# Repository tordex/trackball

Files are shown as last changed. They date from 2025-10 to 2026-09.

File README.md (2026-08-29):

# Tordex Trackball Firmware

Firmware for a custom ESP32-S3 wireless trackball using a PAW3395 optical sensor and BLE HID.

## Highlights

- BLE HID mouse
- PAW3395 motion sensor (SPI)
- SSD1306 OLED status/config UI (I2C)
- Battery monitoring and BLE battery level reporting
- Vertical and horizontal scrolling
- High-resolution scrolling mode
- DPI presets switchable from hardware button
- Deep sleep on inactivity with GPIO wakeup

## Hardware

- MCU: ESP32-S3
- Sensor: PAW3395
- Display: SSD1306 OLED (I2C address `0x3C`)
- Buttons: 6 total
	- `BTN1`, `BTN2`, `BTN3` (main mouse buttons)
	- `MODE` (scroll mode toggle)
	- `SCROLL` (hold/lock scroll and button lock behavior)
	- `CFG` (DPI preset switch)

Pin mapping is defined in `main/pins.h`.

## Software Requirements

- ESP-IDF `v5.5.x`
- CMake `>= 3.16`

## Build and Flash

1. Open an ESP-IDF environment shell.
2. Set target (first time only):

```bash
idf.py set-target esp32s3
```

3. Build:

```bash
idf.py build
```

4. Flash:

```bash
idf.py -p <PORT> flash
```

5. Optional monitor:

```bash
idf.py -p <PORT> monitor
```

## Runtime Controls

### Pointer

- Roll the trackball to move the pointer.

### Scrolling

- Hold `SCROLL` and roll the ball: temporary scroll mode.
- Click `SCROLL`: toggle locked scroll mode on/off.

### Button Lock (drag lock)

- Press and hold a mouse button.
- Click `SCROLL` to lock that button state.
- Click `SCROLL` again to release all locked buttons.

### DPI Preset

- Click `CFG` to cycle DPI presets.
- Hold `CFG` for one second to forget all saved Bluetooth pairings.

### Scroll Mode and Hi-Res

- Click `MODE` to cycle scroll axis modes:
	- vertical + horizontal
	- vertical only
	- horizontal only
- Hold `MODE` to toggle high-resolution scrolling.

## Project Structure

- `main/app.cpp`: app state machine, input handling, power management
- `main/paw3395/`: PAW3395 sensor driver
- `main/nimble/`: BLE HID implementation
- `main/oled/`: SSD1306 driver and UI rendering
- `main/battery/`: battery measurement and level updates
- `main/button/`: button handling (click/hold/state)

## Configuration Notes

- Build-time settings are in `sdkconfig` and `sdkconfig.defaults`.
- Project-specific Kconfig entries are in `main/Kconfig.projbuild`.
- The default deep sleep timeout is 3 minutes (`180000 ms`) in app config.

## Troubleshooting

- Build fails with missing IDF tools:
	- verify ESP-IDF is exported correctly in your shell
- No serial port found:
	- check cable/data support and device permissions
- Device not discoverable over BLE:
	- erase/reflash and reset the board
	- confirm power and battery voltage are stable

## License

This project is licensed under the MIT License. See [LICENSE](LICENSE) for details.

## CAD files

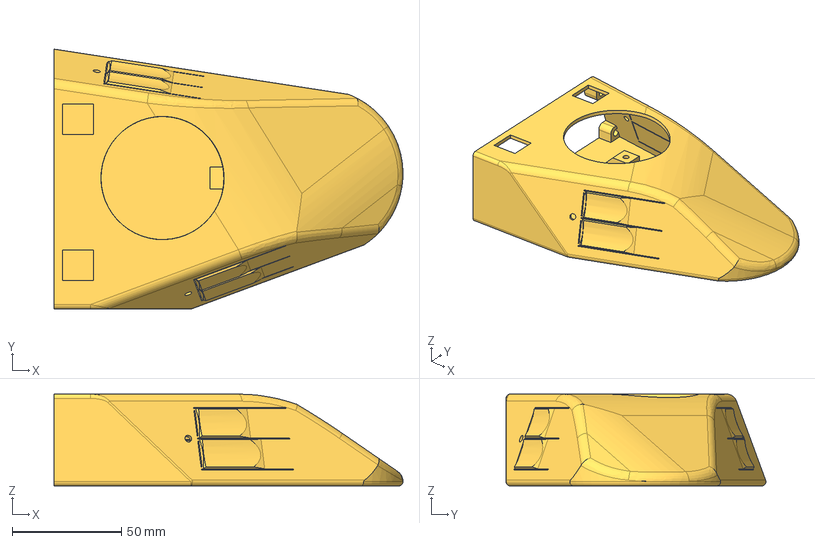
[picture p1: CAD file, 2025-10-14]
hardware/3d/horizontal/Trackball Base - Case v5.step
160.0 x 119.1 x 42.1 mm

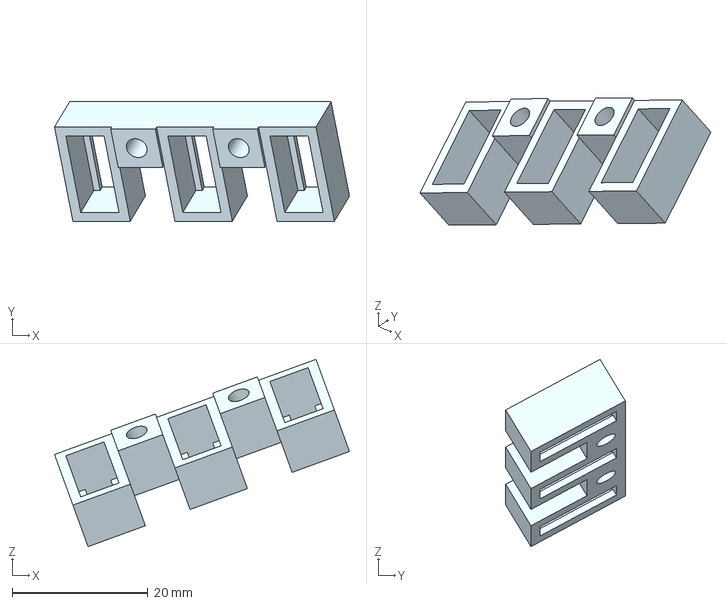
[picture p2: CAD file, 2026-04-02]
hardware/3d/vertical/Vertical - Clickers Holder.step
43.5 x 17.6 x 27.6 mm

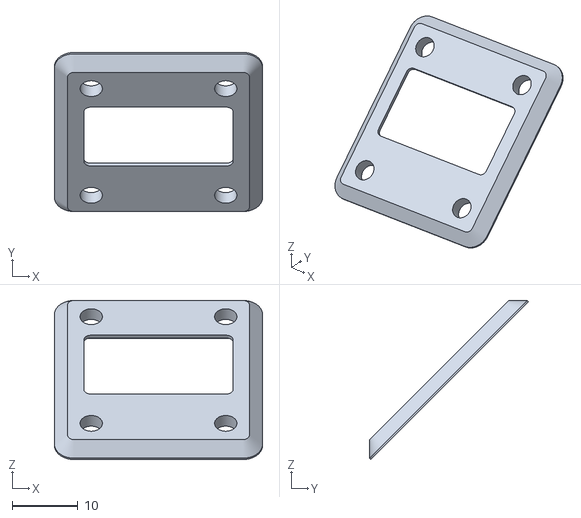
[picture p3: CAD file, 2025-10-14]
hardware/3d/horizontal/OLED Cover.stl
31.7 x 24.3 x 24.3

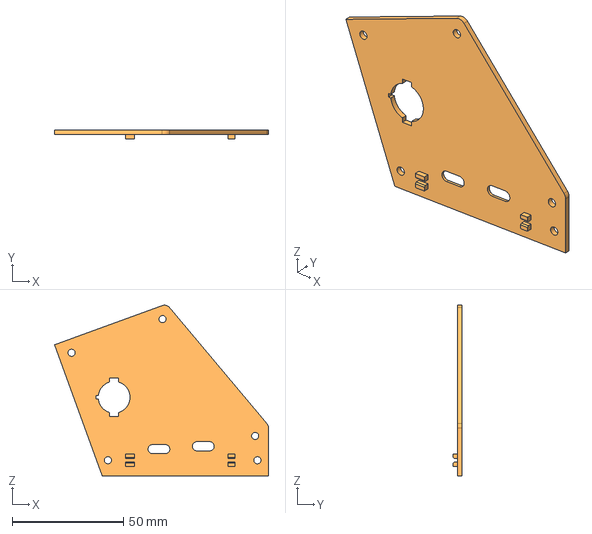
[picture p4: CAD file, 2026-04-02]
hardware/3d/vertical/Vertical - Wall cover.step
96.4 x 4.00 x 76.8 mm

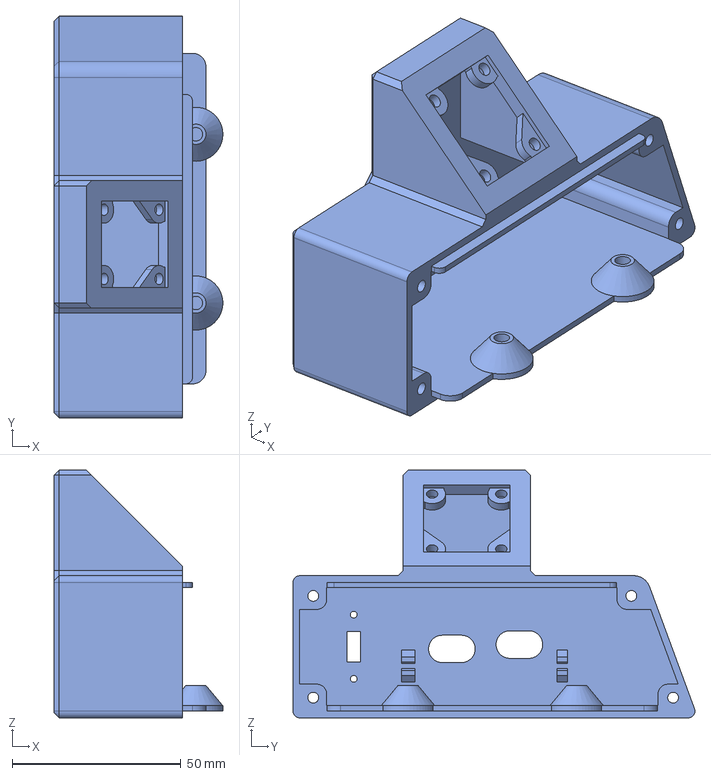
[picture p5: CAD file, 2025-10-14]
hardware/3d/horizontal/Trackball Base - PCB Case.step
50.0 x 119.1 x 73.4 mm

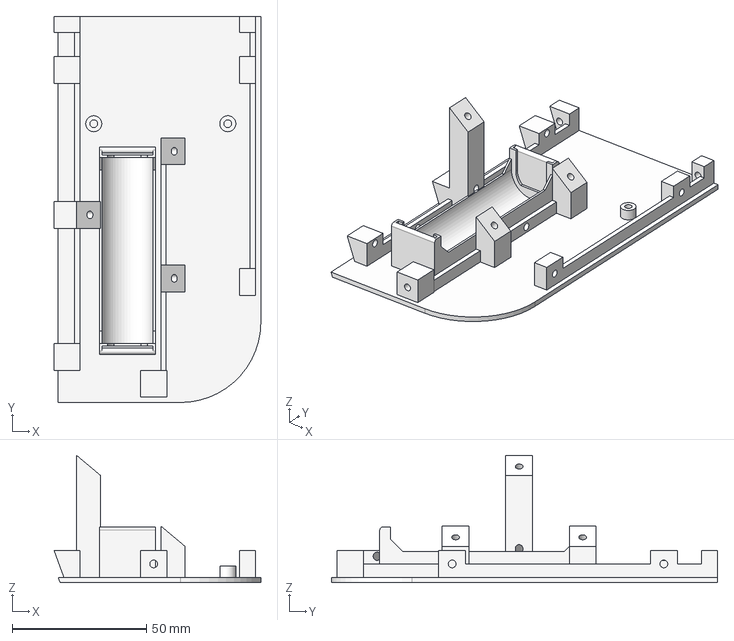
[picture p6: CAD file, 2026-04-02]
hardware/3d/vertical/Vertical - Bottom.step
77.1 x 144.0 x 47.5 mm

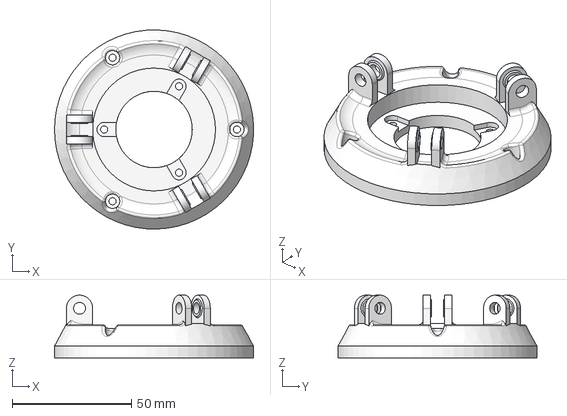
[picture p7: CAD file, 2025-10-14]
hardware/3d/horizontal/Trackball Base - Ball Mount.step
83.4 x 83.5 x 26.3 mm

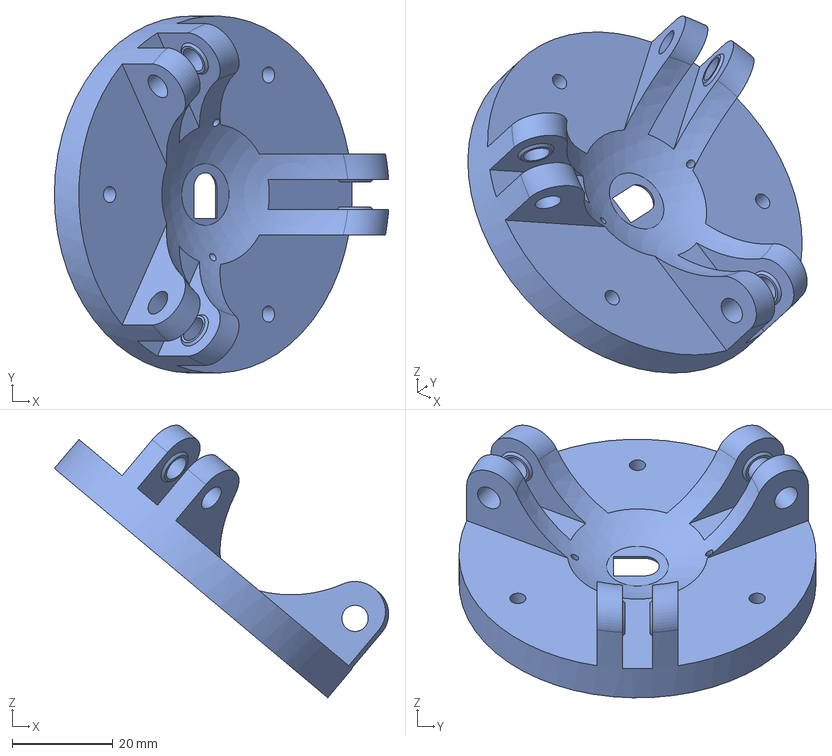
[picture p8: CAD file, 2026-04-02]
hardware/3d/vertical/Vertical - Ball Holder.step
66.2 x 70.7 x 54.0 mm

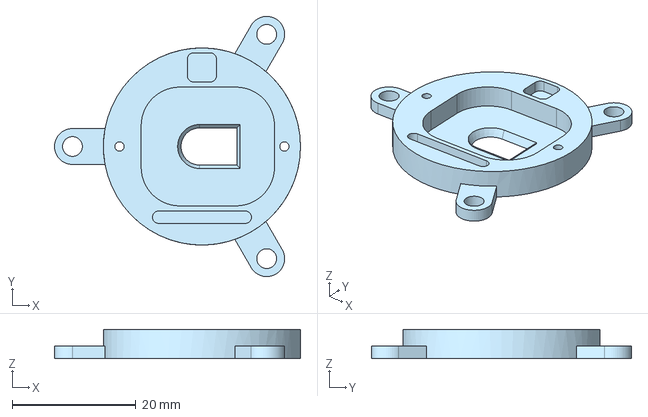
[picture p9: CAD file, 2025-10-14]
hardware/3d/horizontal/Module - Module Mount.step
39.8 x 42.0 x 4.70 mm

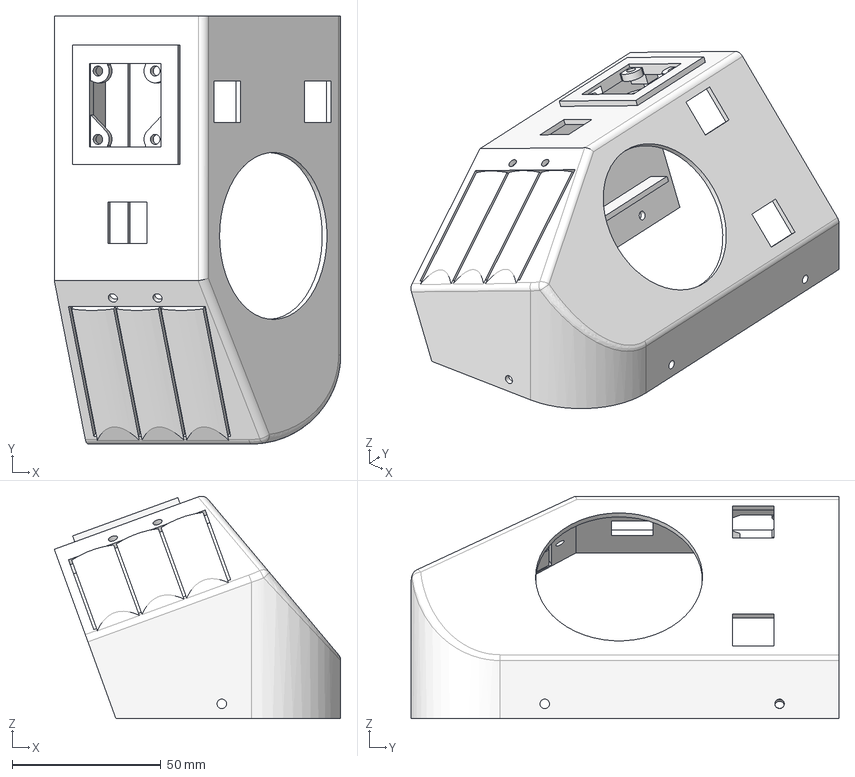
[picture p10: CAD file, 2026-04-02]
hardware/3d/vertical/Vertical - Cover.step
96.4 x 144.0 x 74.8 mm

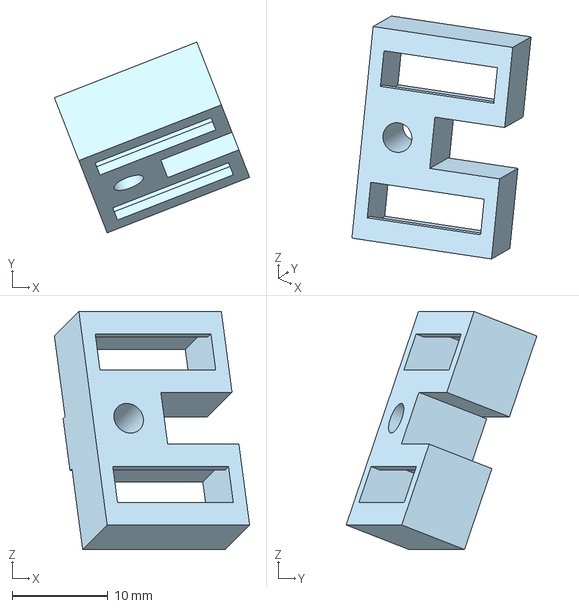
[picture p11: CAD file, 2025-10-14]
hardware/3d/horizontal/Trackball Base - Buttons Mount v4.step
20.4 x 20.0 x 24.9 mm

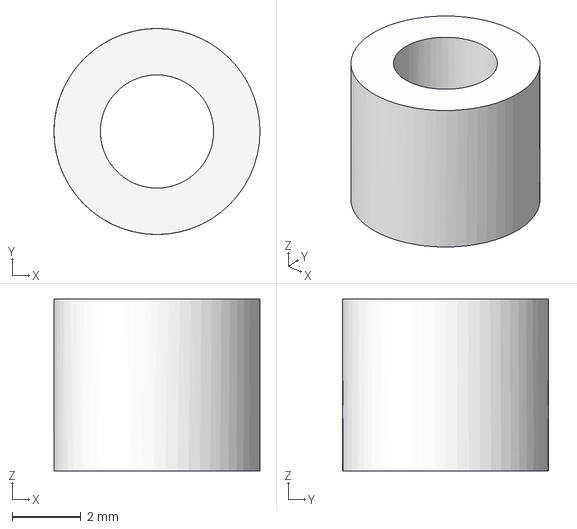
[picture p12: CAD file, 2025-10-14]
hardware/3d/horizontal/Trackball Base - PCB spacer.step
6.00 x 6.00 x 5.00 mm

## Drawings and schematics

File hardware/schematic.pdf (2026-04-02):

# IO7 10 IO8 11 IO9 12 IO10 13 IO11 14 IO12 15 IO13 16 RX 17 TX 18

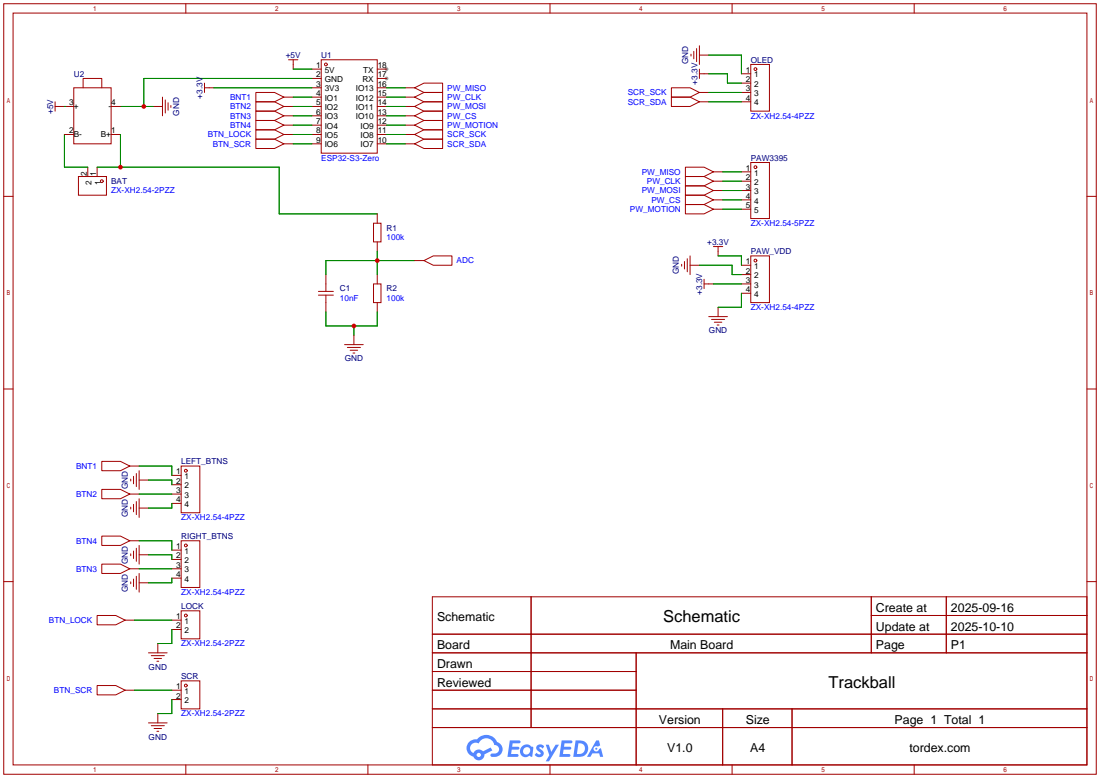
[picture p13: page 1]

Schematic | Schematic | Create at | 2025-09-16

Update at | 2025-10-10

Board | Main Board | Page | P1
Drawn | | Trackball
Reviewed

Version | Size | Page 1 Total 1
V1.0 | A4 | tordex.com

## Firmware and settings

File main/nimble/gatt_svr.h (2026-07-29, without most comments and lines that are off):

#define H_BLEPRPH_
#include <stdbool.h>
#include "nimble/ble.h"
#include "host/ble_hs.h"
#include "host/ble_uuid.h"
#include "services/gatt/ble_svc_gatt.h"
#include "services/gap/ble_svc_gap.h"
#include "services/bas/ble_svc_bas.h"
#include "svc_dis.h"
#include "esp_nimble_hci.h"
#include "nimble/nimble_port.h"
#include "nimble/nimble_port_freertos.h"
#include "host/util/util.h"
#include "modlog/modlog.h"
#ifdef __cplusplus
extern "C"
{
#endif
#define GATT_SVR_SVC_ALERT_UUID               0x1811
#define GATT_SVR_CHR_SUP_NEW_ALERT_CAT_UUID   0x2A47
#define GATT_SVR_CHR_NEW_ALERT                0x2A46
#define GATT_SVR_CHR_SUP_UNR_ALERT_CAT_UUID   0x2A48
#define GATT_SVR_CHR_UNR_ALERT_STAT_UUID      0x2A45
#define GATT_SVR_CHR_ALERT_NOT_CTRL_PT        0x2A44
#define GATT_UUID_HID_SERVICE                 0x1812
#define GATT_UUID_HID_INFORMATION             0x2A4A
#define GATT_UUID_HID_REPORT_MAP              0x2A4B
#define GATT_UUID_HID_CONTROL_POINT           0x2A4C
#define GATT_UUID_HID_REPORT                  0x2A4D
#define GATT_UUID_HID_PROTO_MODE              0x2A4E
#define GATT_UUID_HID_BT_MOUSE_INPUT          0x2A33
#define GATT_UUID_BAT_PRESENT_DESCR           0x2904
#define GATT_UUID_EXT_RPT_REF_DESCR           0x2907
#define GATT_UUID_RPT_REF_DESCR               0x2908
#define BLE_SVC_DIS_MODEL_NUMBER_DEFAULT      "0x0102"
#define BLE_SVC_DIS_SERIAL_NUMBER_DEFAULT     "0x0001"
#define BLE_SVC_DIS_FIRMWARE_REVISION_DEFAULT "0x1409"
#define BLE_SVC_DIS_HARDWARE_REVISION_DEFAULT "0x0001"
#define BLE_SVC_DIS_SOFTWARE_REVISION_DEFAULT "0x1409"
#define BLE_SVC_DIS_MANUFACTURER_NAME_DEFAULT "tordex"
#define BLE_SVC_DIS_SYSTEM_ID_DEFAULT         "esp32"
#define BLE_SVC_DIS_PNP_INFO_DEFAULT                                                                                   \
    {0x04, 0x24, 0x56, 0x00, 0x01, 0x00, 0x01}
#define BLE_SVC_DIS_MODEL_NUMBER_READ_PERM      0
#define BLE_SVC_DIS_SERIAL_NUMBER_READ_PERM     0
#define BLE_SVC_DIS_HARDWARE_REVISION_READ_PERM 0
#define BLE_SVC_DIS_FIRMWARE_REVISION_READ_PERM 0
#define BLE_SVC_DIS_SOFTWARE_REVISION_READ_PERM 0
#define BLE_SVC_DIS_MANUFACTURER_NAME_READ_PERM 0
#define BLE_SVC_DIS_SYSTEM_ID_READ_PERM         0
#define HID_PROTOCOL_MODE_LEN                   1 // HID Protocol Mode
#define HID_INFORMATION_LEN                     4 // HID Information
#define HID_REPORT_REF_LEN                      2 // HID Report Reference Descriptor
#define HID_EXT_REPORT_REF_LEN                  2 // External Report Reference Descriptor
#define HID_RPT_ID_MOUSE_IN                     1 // Mouse input report ID from report map
#define HID_RPT_ID_FEATURE                      1 // Feature report ID from report map
#define HID_BOOT_MOUSE_IN                       8 // Mouse input report ID
#define HID_REPORT_TYPE_INPUT                   1
#define HID_REPORT_TYPE_OUTPUT                  2
#define HID_REPORT_TYPE_FEATURE                 3
#define HID_CC_RPT_SET_NUMERIC(s, x)                                                                                   \
    (s)[0] &= HID_CC_RPT_NUMERIC_BITS;                                                                                 \
    (s)[0] |= (x)
#define HID_CC_RPT_SET_CHANNEL(s, x)                                                                                   \
    (s)[0] &= HID_CC_RPT_CHANNEL_BITS;                                                                                 \
    (s)[0] |= ((x) & 0x03) << 4
#define HID_CC_RPT_SET_VOLUME(s, x)                                                                                    \
    (s)[0] &= HID_CC_RPT_VOLUME_BITS;                                                                                  \
    (s)[0] |= (x)
#define HID_CC_RPT_SET_BUTTON(s, x)                                                                                    \
    (s)[1] &= HID_CC_RPT_BUTTON_BITS;                                                                                  \
    (s)[1] |= (x)
#define HID_CC_RPT_SET_SELECTION(s, x)                                                                                 \
    (s)[1] &= HID_CC_RPT_SELECTION_BITS;                                                                               \
    (s)[1] |= ((x) & 0x03) << 4
#define HIDD_LE_REPORT_MOUSE_SIZE      (9)
#define HIDD_LE_BATTERY_LEVEL_SIZE     (1)
#define HIDD_LE_REPORT_FEATURE         (1)
#define HID_FLAGS_REMOTE_WAKE          0x01 // RemoteWake
#define HID_FLAGS_NORMALLY_CONNECTABLE 0x02 // NormallyConnectable
#define HID_CMD_SUSPEND                0x00 // Suspend
#define HID_CMD_EXIT_SUSPEND           0x01 // Exit Suspend
#define HID_PROTOCOL_MODE_BOOT         0x00 // Boot Protocol Mode
#define HID_PROTOCOL_MODE_REPORT       0x01 // Report Protocol Mode
#define HID_KBD_FLAGS                  HID_FLAGS_REMOTE_WAKE
#define HI_UINT16(a)                   (((a) >> 8) & 0xFF)
#define LO_UINT16(a)                   ((a) & 0xFF)
#define DEFAULT_MIN_KEY_SIZE           0
#define NVS_IO_CAP_NUM                 "io_cap_number"
#define DEFAULT_IO_CAP                 BLE_HS_IO_NO_INPUT_OUTPUT
#define HID_MOUSE_APPEARENCE           0x03c2 // appearance field in advertising packet
    struct ble_hs_cfg;
    struct ble_gatt_register_ctxt;
    struct prf_char_pres_fmt
    {
        uint8_t format;
        uint8_t exponent;
        uint16_t unit;
        uint8_t name_space;
        uint16_t description;
    } __attribute__((packed));
    enum attr_handles
    {
        HANDLE_BATTERY_LEVEL,         //  0
        HANDLE_DIS_MODEL_NUMBER,      //  1
        HANDLE_DIS_SERIAL_NUMBER,     //  2
        HANDLE_DIS_HARDWARE_REVISION, //  3
        HANDLE_DIS_FIRMWARE_REVISION, //  4
        HANDLE_DIS_SOFWARE_REVISION,  //  5
        HANDLE_DIS_MANUFACTURER_NAME, //  6
        HANDLE_DIS_SYSTEM_ID,         //  7
        HANDLE_DIS_PNP_INFO,          //  8
        HANDLE_HID_INFORMATION,       //  9
        HANDLE_HID_CONTROL_POINT,     // 10
        HANDLE_HID_REPORT_MAP,        // 11
        HANDLE_HID_PROTO_MODE,        // 12
        HANDLE_HID_MOUSE_REPORT,      // 13
        HANDLE_HID_BOOT_MOUSE_REPORT, // 19
        HANDLE_HID_FEATURE_REPORT,    // 20
        HANDLE_HID_COUNT              // 21
    };
    struct report_reference_table
    {
        int     id;
        uint8_t hidReportRef[HID_REPORT_REF_LEN];
    } __attribute__((packed));
    void gatt_svr_register_cb(struct ble_gatt_register_ctxt* ctxt, void* arg);
    int  gatt_svr_init(void);
    void gatt_svr_deinit(void);
    int hid_svr_chr_access(uint16_t conn_handle, uint16_t attr_handle, struct ble_gatt_access_ctxt* ctxt, void* arg);
    int ble_svc_report_access(uint16_t conn_handle, uint16_t attr_handle, struct ble_gatt_access_ctxt* ctxt, void* arg);
    int ble_svc_battery_access(uint16_t conn_handle, uint16_t attr_handle, struct ble_gatt_access_ctxt* ctxt,
                               void* arg);
    int ble_svc_dis_access(uint16_t conn_handle, uint16_t attr_handle, struct ble_gatt_access_ctxt* ctxt, void* arg);
    extern const uint8_t Hid_report_map[];
    extern size_t Hid_report_map_size;
    extern uint16_t Svc_char_handles[];
    extern const struct ble_gatt_svc_def Gatt_svr_included_services[];
    extern const struct ble_gatt_svc_def Gatt_svr_svcs[];
    extern const uint8_t HidInfo[];
    extern uint16_t HidExtReportRefDesc;
    extern uint8_t  HidProtocolMode;
    extern struct report_reference_table Hid_report_ref_data[];
    extern size_t                        Hid_report_ref_data_count;
    extern struct prf_char_pres_fmt Battery_level_units;
    extern struct ble_svc_dis_data Hid_dis_data;
#ifdef __cplusplus
}
#endif

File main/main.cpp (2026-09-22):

#include <stdio.h>
#include <stdlib.h>
#include <string.h>
#include "freertos/FreeRTOS.h"
#include "freertos/task.h"
#include "freertos/event_groups.h"
#include "esp_system.h"
#include "esp_wifi.h"
#include "esp_event.h"
#include "esp_log.h"
#include "paw3395.h"
#include "pins.h"
#include <freertos/queue.h>
#include "button.h"
#include "hid_func.h"
#include "app.h"

app* g_app = nullptr;

void hid_on_connection_changed()
{
    g_app->send_event(app_event_update_connection_state);
}

extern "C" void app_main(void)
{
    esp_log_level_set("NimBLE", ESP_LOG_WARN);
    // esp_log_level_set(HID_DEMO_TAG, ESP_LOG_MAX);
    // esp_log_level_set("BLE_HID_MOUSE", ESP_LOG_MAX);

    gpio_install_isr_service(0);

    g_app = new app();
    g_app->init();
    g_app->loop();
}

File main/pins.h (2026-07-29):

#ifndef __PINS__H__
#define __PINS__H__

#define PIN_NUM_MISO    GPIO_NUM_13
#define PIN_NUM_MOSI    GPIO_NUM_11
#define PIN_NUM_CLK     GPIO_NUM_12
#define PIN_NUM_CS      GPIO_NUM_10
#define PIN_NUM_MOTION  GPIO_NUM_9

#define PIN_NUM_I2C_SDA GPIO_NUM_7
#define PIN_NUM_I2C_SCL GPIO_NUM_8

#define PIN_BTN1        GPIO_NUM_1
#define PIN_BTN2        GPIO_NUM_2
#define PIN_BTN3        GPIO_NUM_3
#define PIN_BTN_MODE    GPIO_NUM_6
#define PIN_BTN_SCROLL  GPIO_NUM_5
#define PIN_BTN_CFG     GPIO_NUM_4

#endif // __PINS__H__

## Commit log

2025-08-08 Added buttons and h-weel
2025-08-11 Aproved buttons handling
2025-08-12 Feat: Click lock key to lock the button or scroll
2025-08-28 Added led control
2025-08-28 Remove LED report support from HID report mapping
2025-08-28 Refactor HID Device Profile: Remove Keyboard and Consumer Control Support
    - Removed keyboard input report handling and associated functions from the HID device profile.
    - Eliminated consumer control report handling and related structures.
    - Updated HID report mapping to focus solely on mouse input.
    - Cleaned up unnecessary definitions and constants related to keyboard and consumer control.
    - Adjusted GATT database and report references to reflect the removal of keyboard and consumer control reports.
2025-09-01 Switch to the NimBLE
2025-09-07 Refactor button handling and add motion detection for paw3395 sensor
    - Introduced event-driven button handling using a queue for better responsiveness.
    - Added motion detection capabilities in the paw3395 class with ISR support.
    - Updated button class to include callback functions for state changes and clicks.
2025-09-08 Send buttons on second click the lock key
2025-09-09 Enhance button state change handling by including lock state checks
2025-10-03 Refactor lock state handling in paw3395_task to simplify button event processing and LED color logic
2025-10-14 Add OLED display support and UI enhancements
    - Implement SSD1306 driver for OLED displays with initialization, drawing, and bitmap support.
    - Introduce font handling for rendering text on the display.
    - Create a trackball UI class to manage connection states, battery levels, and UI states.
    - Add functions to draw status lines, battery indicators, and handle different UI states (default, scroll lock, lock buttons).
    - Integrate RSSI display functionality to show connection strength.
    - Update pin definitions to include I2C pins for OLED communication.
2025-10-14 Added 3D models and PCB gerber
    [Garden Controller - OLED Cover.stl, Module - Module Mount.step, Trackball Base - Ball Mount.step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]
2025-10-29 Remove debug print statements from button state change handlers
2026-04-02 Added schematic and 3d files for vertical trackball
    [Module - Module Mount.step, OLED Cover.stl, Trackball Base - Ball Mount.step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]
2026-04-04 Change DPI, enable/disable H/V/HighRes scrolling
    Also lock sensor DPI during scrolling.
    Enable/disable H/V scrolling - cycle by pressing the Scroll Mode button.
    Enable/Disable High Resolution Scrolling - hold down the Scroll Mode button.
    Change DPI - press config button
2026-07-19 Enhance sensor initialization with error handling and retries; update motion pin initialization to return error status
    [app.cpp, paw3395.cpp]
2026-07-22 Refactor app initialization and event handling; enhance button management and sensor integration
2026-07-23 Reduce power consumption
    * Turn off the second CPU core
    * Adjust BLE adv latency
    * Enable Power Management
    * Enable Dynamic Frequency Scaling
    * Enable watchdog (WDT)
2026-07-27 Refactor battery voltage handling; implement level hysteresis and improve charge level calculation
2026-07-30 Update NVS storage version handling; replace hardcoded version with constant
    [app.cpp]
2026-08-30 Initialize HID subsystem and create mutex for device access
2026-08-30 Remove unnecessary SPI_DEVICE_NO_DUMMY flag from device configuration
2026-09-22 Refactor PAW3395 initialization and motion handling; improve error logging and add stop functionality
    [app.cpp, main.cpp, paw3395.cpp]
2026-09-22 Change wheel and ac_pan types to int16_t in sensor_motion_callback for improved precision
2026-09-24 Refactor sensor motion callback to adjust wheel and ac_pan values; update DPI settings in menu navigation

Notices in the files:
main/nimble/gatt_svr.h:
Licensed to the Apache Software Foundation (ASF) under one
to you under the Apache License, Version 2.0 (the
